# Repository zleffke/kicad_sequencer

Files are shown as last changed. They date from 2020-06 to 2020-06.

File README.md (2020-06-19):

# kicad_sequencer
Transverter sequencer circuit.  Based on W6PQL Design.

### Credit where its due:
[Relay Sequencer](https://www.w6pql.com/relay_sequencer.htm) from W6PQL.

#### Versions:

w6pql_sequencer - this design is nearly identical to W6PQL's at the link above. Just a kicad implementation and variations on the layout for my own projects.

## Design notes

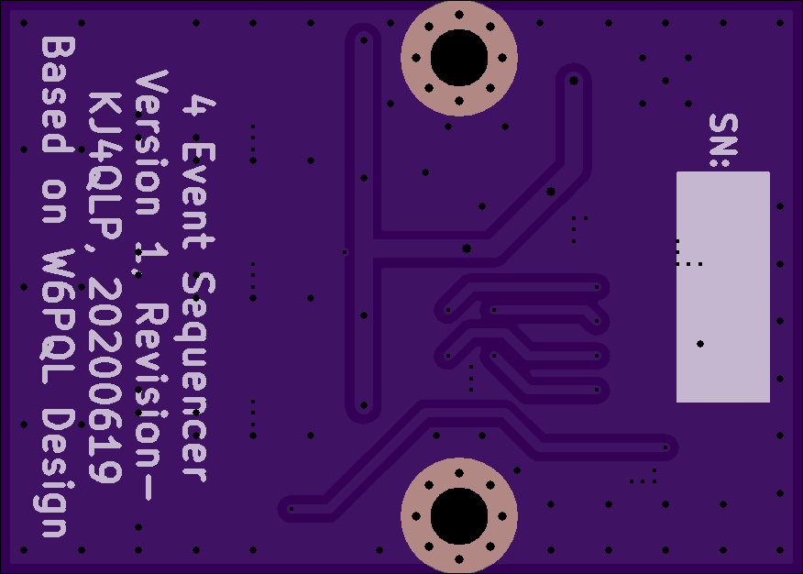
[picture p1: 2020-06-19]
w6pql_sequencer/rev-/osh_park_bottom_view.png

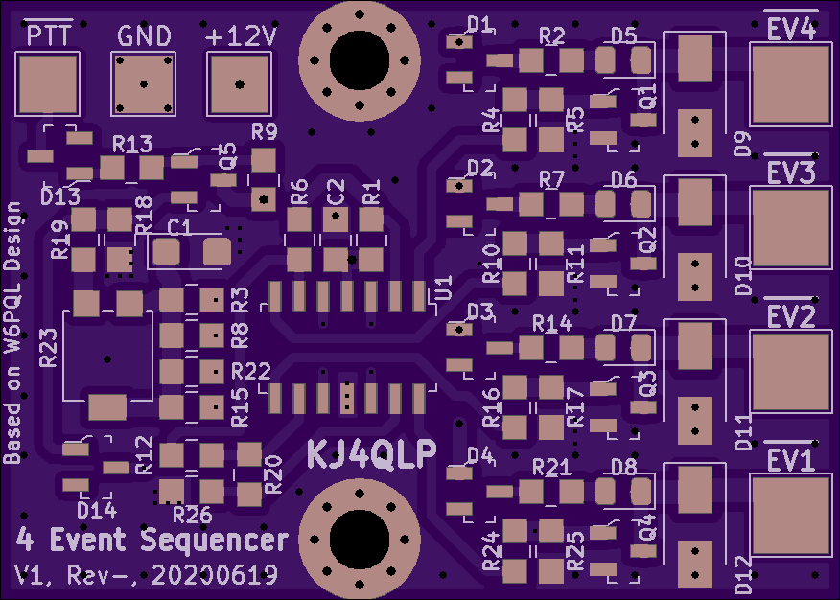
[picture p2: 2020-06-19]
w6pql_sequencer/rev-/osh_park_top_view.png

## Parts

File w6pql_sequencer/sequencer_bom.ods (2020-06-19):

Supplier | Part # | Supplier Description | U/L | Qty | Unit Cost | Total Cost | LINK | Board Identifier | Comment | Order Status
Digikey | BAS16LT1GOSCT-ND | Diode Standard 100V 200mA (DC) Surface Mount SOT-23-3 (TO-236) | ea | 100 | $0.04 | $3.74 | LINK (https://www.digikey.com/product-detail/en/on-semiconductor/BAS16LT1G/BAS16LT1GOSCT-ND/917796) | D1, D2
Digikey | 3314G-502ECT-ND | 5 kOhms 0.25W, 1/4W Gull Wing Surface Mount Trimmer Potentiometer Cermet 1 Turn Top Adjustment | ea | 10 | $1.91 | $19.14 | LINK (https://www.digikey.com/product-detail/en/bourns-inc/3314G-1-502E/3314G-502ECT-ND/86461)
Digikey | MMBT2907ALT1GOSCT-ND | Bipolar (BJT) Transistor PNP 60V 600mA 200MHz 300mW Surface Mount SOT-23-3 (TO-236) | ea | 100 | $0.06 | $5.61 | LINK (https://www.digikey.com/product-detail/en/on-semiconductor/MMBT2907ALT1G/MMBT2907ALT1GOSCT-ND/1139812)
Digikey | MMBT6427LT1GOSCT-ND | Bipolar (BJT) Transistor NPN - Darlington 40V 500mA 225mW Surface Mount SOT-23-3 (TO-236) | ea | 100 | $0.08 | $7.59 | LINK (https://www.digikey.com/product-detail/en/on-semiconductor/MMBT6427LT1G/MMBT6427LT1GOSCT-ND/1139827)
Digikey | 311-499CRCT-ND | 499 Ohms ±1% 0.125W, 1/8W Chip Resistor 0805 (2012 Metric) Moisture Resistant Thick Film | ea | 100 | $0.02 | $1.63 | LINK (https://www.digikey.com/products/en?keywords=311-499CRCT-ND)
Digikey | 311-1.00KCRCT-ND | 1 kOhms ±1% 0.125W, 1/8W Chip Resistor 0805 (2012 Metric) Moisture Resistant Thick Film | ea | 100 | $0.02 | $1.63 | LINK (https://www.digikey.com/product-detail/en/yageo/RC0805FR-071KL/311-1-00KCRCT-ND/730391)
Digikey | 541-4321-1-ND | 5 kOhms ±1% 0.125W, 1/8W Chip Resistor 0805 (2012 Metric) Automotive AEC-Q200 Thick Film | ea | 100 | $0.05 | $4.96 | LINK (https://www.digikey.com/product-detail/en/vishay-dale/CRCW08055K00FKTA/541-4321-1-ND/8565934)
Digikey | 311-10.0KCRCT-ND | 10 kOhms ±1% 0.125W, 1/8W Chip Resistor 0805 (2012 Metric) Moisture Resistant Thick Film | ea | 100 | $0.02 | $1.63 | LINK (https://www.digikey.com/product-detail/en/yageo/RC0805FR-0710KL/311-10-0KCRCT-ND/730482)
Digikey | 311-100KCRCT-ND | 100 kOhms ±1% 0.125W, 1/8W Chip Resistor 0805 (2012 Metric) Moisture Resistant Thick Film | ea | 100 | $0.02 | $1.63 | LINK (https://www.digikey.com/product-detail/en/yageo/RC0805FR-07100KL/311-100KCRCT-ND/730491)
Digikey | 399-19155-1-ND | 2.2µF ±10% 50V Ceramic Capacitor X7R 1206 (3216 Metric) | ea | 10 | $0.22 | $2.21 | LINK (https://www.digikey.com/product-detail/en/kemet/C1206C225K5RACAUTO7210/399-19155-1-ND/9666633)
Digikey | 399-10447-1-ND | 2.2µF Molded Tantalum Capacitors 35V 1206 (3216 Metric) 4.5Ohm | ea | 10 | $0.44 | $4.41 | LINK (https://www.digikey.com/product-detail/en/kemet/T491A225K035AT/399-10447-1-ND/3907815)
Digikey | LM324DR2GOSCT-ND | General Purpose Amplifier 4 Circuit 14-SOIC | ea | 10 | $0.36 | $3.56 | LINK (https://www.digikey.com/product-detail/en/on-semiconductor/LM324DR2G/LM324DR2GOSCT-ND/917944)
 |  |  |  |  | Subtotal | $57.74

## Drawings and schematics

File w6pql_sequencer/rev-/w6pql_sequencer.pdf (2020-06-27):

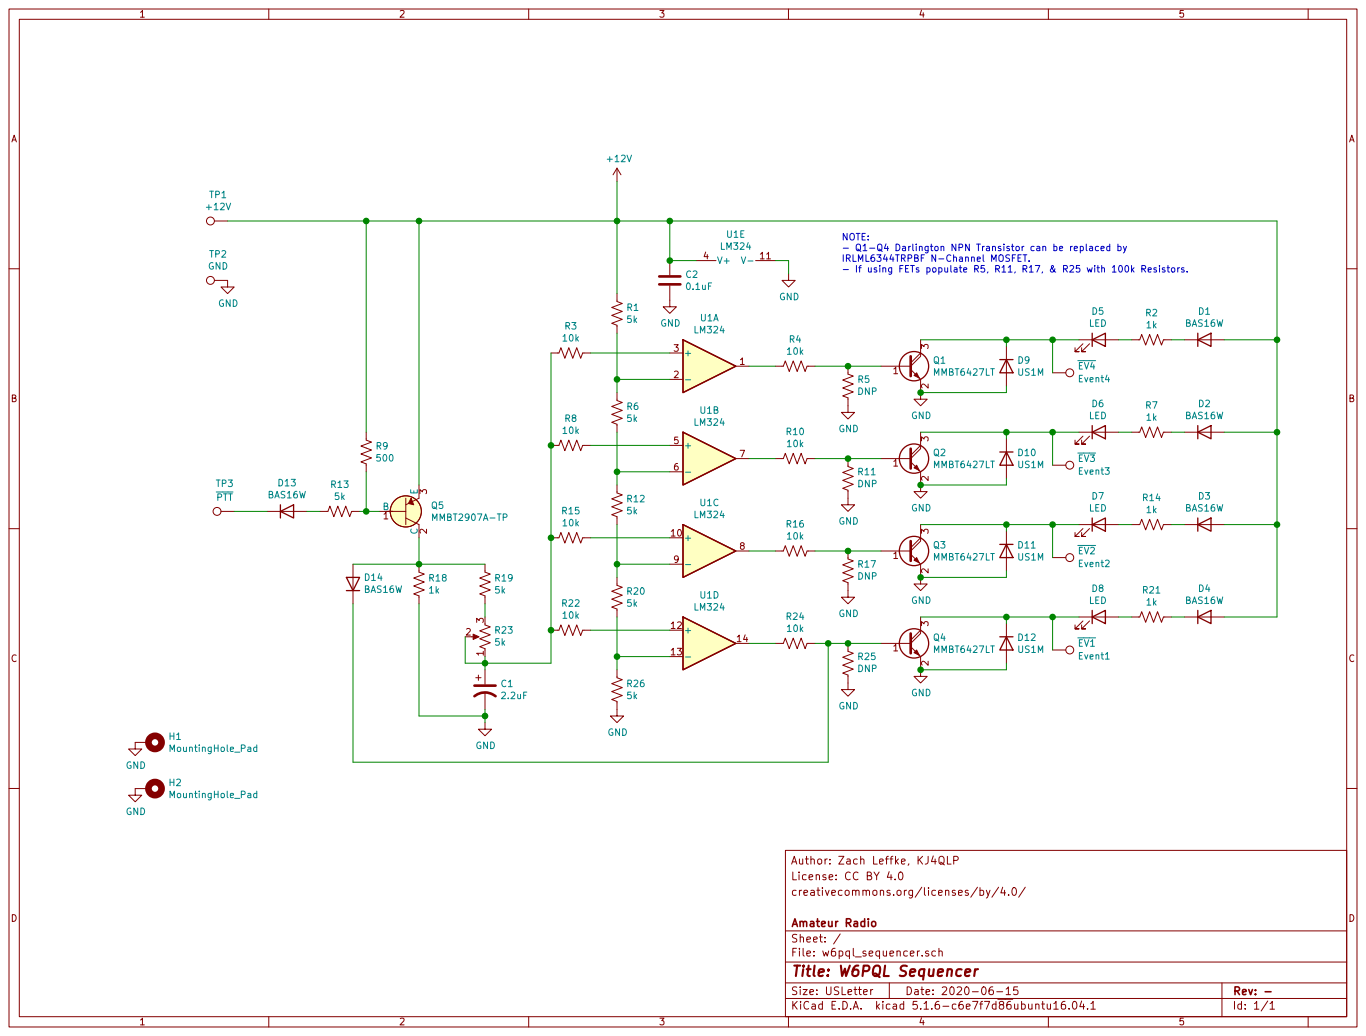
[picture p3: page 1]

R5 DNP R11 DNP R17 DNP R25 DNP R24

NOTE: - Q1-Q4 Darlington NPN Transistor can be replaced by

IRLML6344TRPBF N-Channel MOSFET. - If using FETs populate R5, R11, R17, & R25 with 100k Resistors.

creativecommons.org/licenses/by/4.0/ License: CC BY 4.0 Author: Zach Leffke, KJ4QLP

File: w6pql_sequencer.sch Sheet: / Amateur Radio

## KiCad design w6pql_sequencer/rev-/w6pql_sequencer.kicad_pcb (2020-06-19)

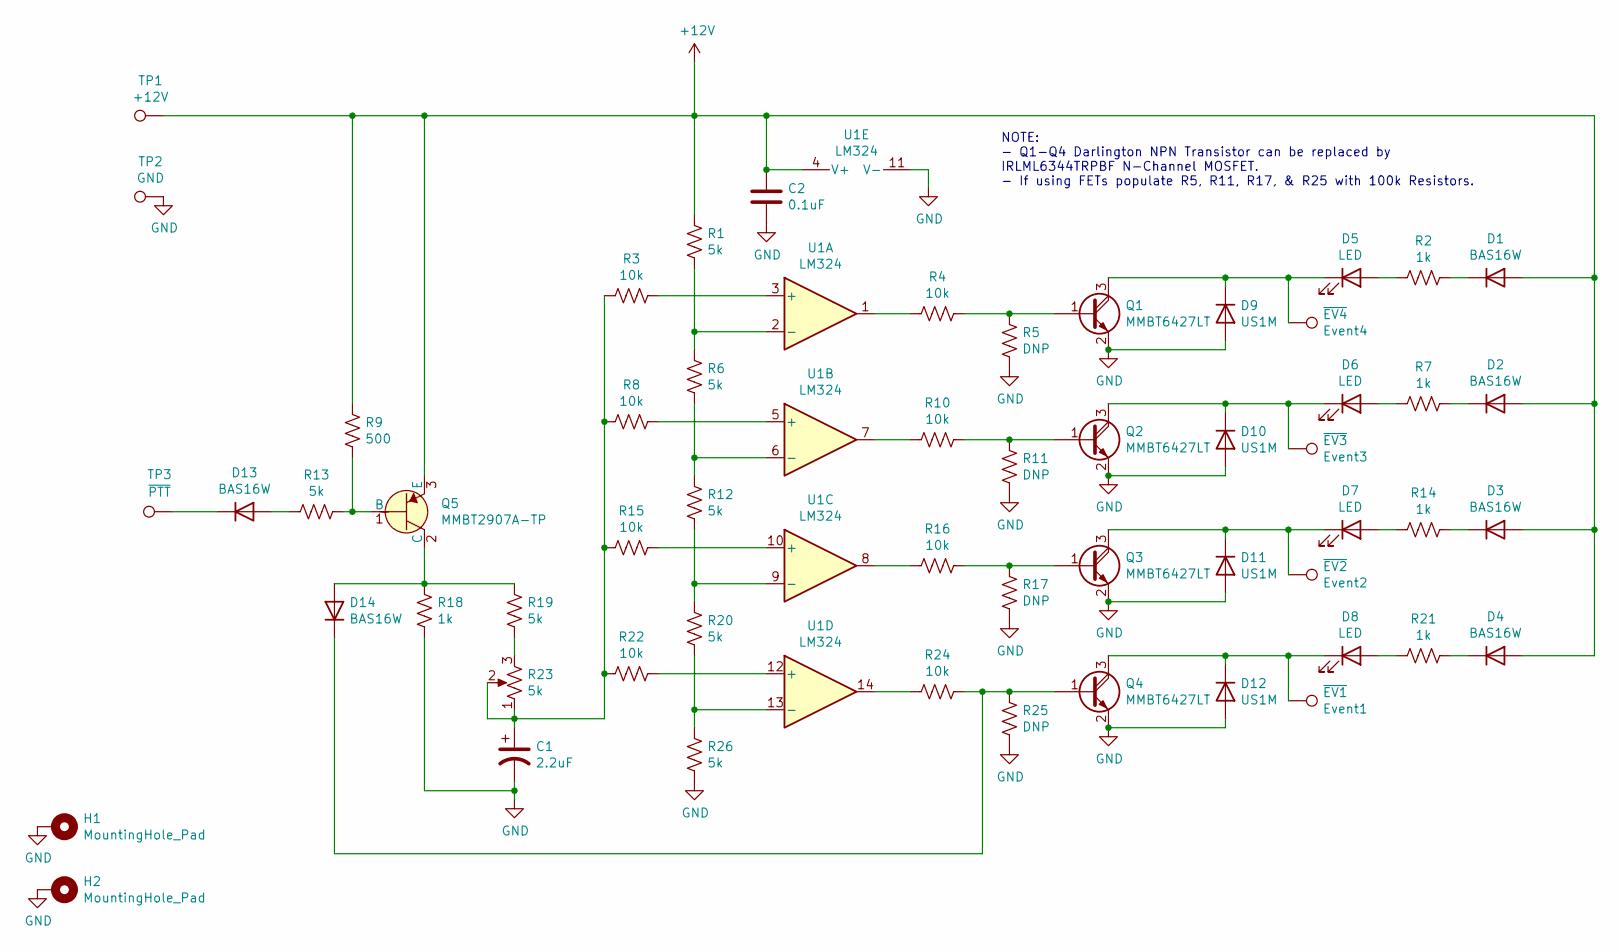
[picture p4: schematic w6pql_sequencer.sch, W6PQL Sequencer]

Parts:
C1: 2.2uF; CP_EIA-3216-18_Kemet-A
C2: 0.1uF; 0805
D1, D2, D3, D4, D13, D14: BAS16W; SOT-23-3
D5, D6, D7, D8: LED; LED_0805_2012Metric
D9, D10, D11, D12: US1M; D_SMA
H1, H2: MountingHole_Pad; MountingHole_3.2mm_M3_Pad_Via
Q1, Q2, Q3, Q4: MMBT6427LT; SOT-23-3
Q5: MMBT2907A-TP; SOT-23-3; MPN MMBT2907A-TP; Digi-Key_PN MMBT2907A-TPMSCT-ND
R1, R6, R12, R13, R19, R20, R26: 5k; 0805
R2, R7, R14, R18, R21: 1k; 0805
R3, R4, R8, R10, R15, R16, R22, R24: 10k; 0805
R5, R11, R17, R25: DNP; 0805
R9: 500; 0805
R23: 5k; Potentiometer_Bourns_3314G_Vertical
TP1: +12V; TestPoint_Pad_3.0x3.0mm
TP2: GND; TestPoint_Pad_3.0x3.0mm
TP3: ~PTT; TestPoint_Pad_3.0x3.0mm
U1: LM324; SOIC-14_W3.9mm
~EV1: Event1; TestPoint_Pad_4.0x4.0mm
~EV2: Event2; TestPoint_Pad_4.0x4.0mm
~EV3: Event3; TestPoint_Pad_4.0x4.0mm
~EV4: Event4; TestPoint_Pad_4.0x4.0mm

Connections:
+12V: C2.1, D1.1 (A), D2.1 (A), D3.1 (A), D4.1 (A), Q5.3 (E), R1.1, R9.1, TP1.1, U1.4 (V+)
GND: C1.2, C2.2, D9.2 (A), D10.2 (A), D11.2 (A), D12.2 (A), H1.1, H2.1, Q1.2 (E), Q2.2 (E), Q3.2 (E), Q4.2 (E), R5.1, R11.1, R17.1, R18.2, R25.1, R26.2, TP2.1, U1.11 (V-)
unnamed: C1.1, R3.2, R8.2, R15.2, R22.2, R23.1, R23.2
unnamed: D1.3 (K), R2.1
unnamed: D2.3 (K), R7.1
unnamed: D3.3 (K), R14.1
unnamed: D4.3 (K), R21.1
unnamed: D5.1 (K), D9.1 (K), Q1.3 (C), ~EV4.1
unnamed: D5.2 (A), R2.2
unnamed: D6.2 (A), R7.2
unnamed: D7.2 (A), R14.2
unnamed: D8.2 (A), R21.2
unnamed: D6.1 (K), D10.1 (K), Q2.3 (C), ~EV3.1
unnamed: D7.1 (K), D11.1 (K), Q3.3 (C), ~EV2.1
unnamed: D8.1 (K), D12.1 (K), Q4.3 (C), ~EV1.1
unnamed: D13.1 (A), R13.2
unnamed: D13.3 (K), TP3.1
unnamed: D14.1 (A), Q5.2 (C), R18.1, R19.1
unnamed: D14.3 (K), Q4.1 (B), R24.1, R25.2
unnamed: Q1.1 (B), R4.1, R5.2
unnamed: Q2.1 (B), R10.1, R11.2
unnamed: Q3.1 (B), R16.1, R17.2
unnamed: Q5.1 (B), R9.2, R13.1
unnamed: R1.2, R6.1, U1.2 (-)
unnamed: R3.1, U1.3 (+)
unnamed: R4.2, U1.1
unnamed: R8.1, U1.5 (+)
unnamed: R10.2, U1.7
unnamed: R6.2, R12.1, U1.6 (-)
unnamed: R12.2, R20.1, U1.9 (-)
unnamed: R15.1, U1.10 (+)
unnamed: R16.2, U1.8
unnamed: R19.2, R23.3
unnamed: R20.2, R26.1, U1.13 (-)
unnamed: R22.1, U1.12 (+)
unnamed: R24.2, U1.14

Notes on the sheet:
NOTE: - Q1-Q4 Darlington NPN Transistor can be replaced by IRLML6344TRPBF N-Channel MOSFET. - If using FETs populate R5, R11, R17, & R25 with 100k Resistors.

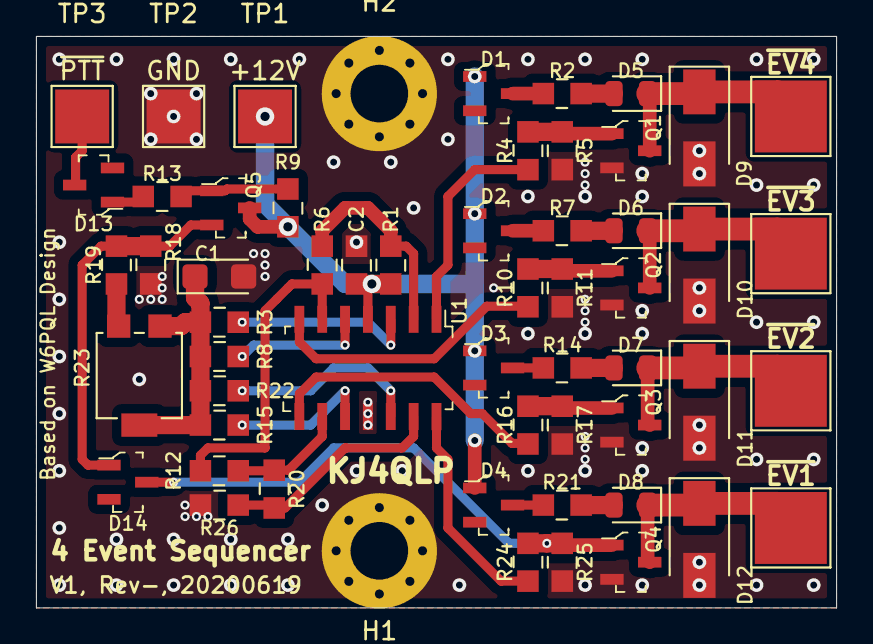
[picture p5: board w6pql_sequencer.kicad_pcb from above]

Board: 2 copper layers, 44.4 x 31.8 mm, 53 parts (0 on the bottom side), 36 nets.

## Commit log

2020-06-19 adding v1, rev-. this commit submitted to osh park.
    [sequencer_bom.ods, w6pql_sequencer.kicad_pcb, w6pql_sequencer.sch]
2020-06-27 adding schematic pdf
